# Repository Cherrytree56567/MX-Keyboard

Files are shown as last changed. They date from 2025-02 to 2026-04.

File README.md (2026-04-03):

# MX Keyboard
A Keyboard I made for Hackboard. It has a built-in USB C Hub and has Hotswap support.
gif

## Info
 - 0.25mm Tolerance
 - Black Case

## Features
 - USB C Hub
 - RP2040
 - 61 Keys
 - Cherry MX Switches
 - Kailh Hotswap Sockets

# CAD
Here are some photos of the CAD 3D Print. It uses M2 Threads that are 6mm long on the top (gray part) and a 1.6mm M2 nut on the bottom plate (blue part) to raise the pcb.
I made the USB-C input and output separate so that they won't be confused and I've used Durock V3 Stabilizers for the spacebar, enter and shift keys. When I made my mini
keyboard last time, I made the holes too tight, so when I soldered the keys, if it was slightly tilted, it wouldn't fit in the case. This time, I added a 1.5mm padding.
<br><br>






Here is a photo of pcb and the case put together without the keys.<br><br>


# PCB
Here are some photos of the PCB. I've made most of the main components to sit on the top, to prevent electromagnetic interference, and I've also uses ground fills.
The diodes and Kailh Hotswap sockets are placed under the board. The Git Repo was pretty messy because I had multiple revisions of the pcb and the case and I didn't
update some parts like the readme. It should be organised now. The wiring was pretty hard becuase it was my first time making a keyboard. I made a mini keyboard, but
there were some more things to worry about when making a full keyboard. I've used USB 2.0 because dealing with impedences was pretty difficult, and I didn't need a
USB 3.0 port anyway. If you want to take an upclose look at the pcb or the schematic, you can look the pdf's on the root of this repo.



pcb_schematic-1

# Firmware
Unfortunatly, I don't know if the code works, because I haven't gotten the PCB yet, but to install it:
 - Install Circuit Python
   - [Download CircuitPython](https://circuitpython.org/board/raspberry_pi_pico/)
   - Plug the Keyboard in
   - Drag the .uf2 into the RP2040 Drive
 - Install KMK
   - [Download KMK](https://github.com/KMKfw/kmk_firmware/archive/refs/heads/master.zip)
   - Unzip it and copy the `kmk` folder from `kmk_firmware-main` to the CIRCUITPY Drive
 - Install Firmware
   - Copy the Code from [src/main.py](https://github.com/Cherrytree56567/MX-Keyboard/raw/refs/heads/main/src/main.py)
   - Create a new file in the CIRCUITPY Drive called `code.py` and paste it in.

# Building
1. Print out the 3D Print and order the PCB
2. Solder all the parts on the PCB
3. Add the Kailh SMD Keys
4. Add the Durock V3 Stabilizers
5. Push the threads and nuts into the PCB using a Soldering Iron
6. Place the PCB in the case and screw it in
7. Install Firmware
<br>
Here is the JLC Ordering Screen


# Bill of Materials
> [!NOTE]
> All Prices are in USD

|Designator |Footprint |Quantity|Value |URL |Price_USD|
|---|---|---|---|---|---|
|C1, C2 |0402 |2 |15p |https://www.lcsc.com/product-detail/C86285.html |$0.36 |
|C10, C8 |0402 |2 |1u |https://www.lcsc.com/product-detail/C435415.html |$0.73 |
|C11, C12, C13, C14, C15, C16, C5, C6, C7, C9|0402 |10 |100n |https://www.lcsc.com/product-detail/C131394.html |$0.29 |
|C23, C24 |0805 |2 |10uF |https://www.lcsc.com/product-detail/C18185764.html |$0.39 |
|C25 |0805 |1 |100nF |https://www.lcsc.com/product-detail/C53084519.html |$0.29 |
|C3, C4 |0805 |2 |10u |https://www.lcsc.com/product-detail/C2167686.html |$0.61 |
|D1, D... |Diode_DO-35 |61 |Diode |https://www.lcsc.com/product-detail/C84410.html |$1.72 |
|D34 |1206 |1 |MBR120VLSFT1G |https://www.lcsc.com/product-detail/C223608.html |$0.70 |
|J1, J2, J4, J5 |USB_C_Receptacle_HRO_TYPE-C-31-M-12 |1 |USB_C_Receptacle_USB2.0|https://www.aliexpress.com/item/1005003285152827.html?mp=1|$4.01 |
|R1, R2 |0805 |2 |5.1K |https://www.lcsc.com/product-detail/C490833.html |$0.76 |
|R14, R15, R16, R17, R18, R19 |0805 |6 |56K |https://www.lcsc.com/product-detail/C21571499.html |$0.52 |
|R3, R5 |0402 |2 |1k |https://www.lcsc.com/product-detail/C852624.html |$0.86 |
|R4 |0402 |1 |DNF | |$0 |
|R6, R7 |0402 |2 |27 |https://www.aliexpress.com/item/1005005433144951.html?mp=1|$2.46 |
|S1 |MX_PCB_1.00u |65 |Key |https://www.aliexpress.com/item/1005003944834891.html?mp=1|$19.06 |
|SW1 |SW_Push_1P1T_NO_Vertical_Wuerth_434133025816|1 |SW_Push |https://www.lcsc.com/product-detail/C221897.html |$0.49 |
|U1 |SOIC-16_4.55x10.3mm_P1.27mm |1 |SL2.1A |https://www.aliexpress.com/item/1005005552905296.html?mp=1|$2.33 |
|U2 |SOT-223-3_TabPin2 |1 |NCP1117-3.3_SOT223 |https://www.lcsc.com/product-detail/C26537.html |$1.31 |
|U3 |SOIC-8_5.23x5.23mm_P1.27mm |1 |W25Q128JVS |https://www.aliexpress.com/item/1005008022185475.html |$4.88 |
|U4 |RP2040-QFN-56 |1 |RP2040 |https://www.lcsc.com/product-detail/C2040.html |$0.95 |
|Y1 |Crystal_SMD_3225-4Pin_3.2x2.5mm |1 |ABM8-272-T3 |https://www.lcsc.com/product-detail/C20625731.html |$1.45 |
|N/A |Standoff |4 |M2X6 |https://www.aliexpress.com/item/1005008551732587.html |$2.04 |
|N/A |Nut |12 |Nut |https://www.aliexpress.com/item/1005008755211193.html |$3.04 |
|N/A |Screw |5 |M2_10mm |https://www.ebay.com.au/itm/363744921549?var=632961986863 |$2.26 |
|N/A |Socket |70 |Kailh |https://www.aliexpress.com/item/1005007225352311.html?mp=1|$0.99 |
|N/A |Stabilizer |1 |Durock_V3_Stabilizers  |https://www.aliexpress.com/item/1005006628741999.html?mp=1|$15.56 |
|N/A |Key_Caps |1 |Black_Line_131 |https://www.aliexpress.com/item/1005007016258336.html?mp=1|$24.62 |
|N/A |PCB |1 |JLC_PCB |https://jlcpcb.com/ |$18.40 |
|N/A |JLCPCB Shipping |1 |JLCPCB_Shipping |https://www.jlcpcb.com |$12.73 |
|N/A |Aliexpress Tax |1 |ALIEXPRESS_TAX |https://www.aliexpress.com |$8.26 |
|N/A |LCSC Shipping |1 |LCSC_Shipping |https://www.lcsc.com |$12.81 |

Total Price: US$142.65

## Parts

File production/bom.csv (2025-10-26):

Designator | Footprint | Quantity | Value | LCSC Part #
C1, C2 | 0402 | 2 | 15p
C10, C8 | 0402 | 2 | 1u
C11, C12, C13, C14, C15, C16, C5, C6, C7, C9 | 0402 | 10 | 100n
C23, C24 | 0805 | 2 | 10uF
C25 | 0805 | 1 | 100nF
C3, C4 | 0805 | 2 | 10u
D1, D10, D11, D12, D13, D14, D15, D16, D17, D18, D19, D2, D20, D21, D22, D23, D24, D25, D26, D27, D28, D29, D3, D30, D31, D32, D33, D37, D38, D39, D4, D40, D41, D42, D43, D44, D45, D46, D47, D48, D49, D5, D50, D51, D52, D53, D54, D55, D56, D57, D58, D59, D6, D61, D63, D67, D7, D71, D72, D8, D9 | Diode_DO-35 | 61 | Diode
D34 | 1206 | 1 | SD1206T020S1R0
J1, J2, J4, J5 | USB_C_Receptacle_HRO_TYPE-C-31-M-12 | 4 | USB_C_Receptacle_USB2.0
R1, R2 | 0805 | 2 | 5.1K
R14, R15, R16, R17, R18, R19 | 0805 | 6 | 56K
R3, R5 | 0402 | 2 | 1k
R4 | 0402 | 1 | DNF
R6, R7 | 0402 | 2 | 27
S1 | SW_Hotswap_Kailh_MX_1.00u | 1 | esc
S10 | SW_Hotswap_Kailh_MX_1.00u | 1 | 3
S11 | SW_Hotswap_Kailh_MX_1.00u | 1 | e
S12 | SW_Hotswap_Kailh_MX_1.00u | 1 | d
S13 | SW_Hotswap_Kailh_MX_1.00u | 1 | 4
S14 | SW_Hotswap_Kailh_MX_1.00u | 1 | r
S15 | SW_Hotswap_Kailh_MX_1.00u | 1 | f
S16 | SW_Hotswap_Kailh_MX_1.00u | 1 | 5
S17 | SW_Hotswap_Kailh_MX_1.00u | 1 | t
S18 | SW_Hotswap_Kailh_MX_1.00u | 1 | g
S19 | SW_Hotswap_Kailh_MX_1.00u | 1 | 6
S2 | SW_Hotswap_Kailh_MX_1.00u | 1 | 1
S20 | SW_Hotswap_Kailh_MX_1.00u | 1 | y
S21 | SW_Hotswap_Kailh_MX_1.00u | 1 | h
S22 | SW_Hotswap_Kailh_MX_1.00u | 1 | 7
S23 | SW_Hotswap_Kailh_MX_1.00u | 1 | u
S24 | SW_Hotswap_Kailh_MX_1.00u | 1 | j
S25 | SW_Hotswap_Kailh_MX_1.00u | 1 | 8
S26 | SW_Hotswap_Kailh_MX_1.00u | 1 | i
S27 | SW_Hotswap_Kailh_MX_1.00u | 1 | k
S28 | SW_Hotswap_Kailh_MX_1.00u | 1 | 9
S29 | SW_Hotswap_Kailh_MX_1.00u | 1 | o
S3 | SW_Hotswap_Kailh_MX_1.00u | 1 | 2
S30 | SW_Hotswap_Kailh_MX_1.00u | 1 | l
S31 | SW_Hotswap_Kailh_MX_1.00u | 1 | 0
S32 | SW_Hotswap_Kailh_MX_1.00u | 1 | p
S33 | SW_Hotswap_Kailh_MX_1.00u | 1 | ;
S37 | SW_Hotswap_Kailh_MX_1.00u | 1 | -
S38 | SW_Hotswap_Kailh_MX_1.00u | 1 | [
S39 | SW_Hotswap_Kailh_MX_1.00u | 1 | '
S4 | SW_Hotswap_Kailh_MX_1.00u | 1 | tab
S40 | SW_Hotswap_Kailh_MX_1.00u | 1 | =
S41 | SW_Hotswap_Kailh_MX_1.00u | 1 | ]
S42 | SW_Hotswap_Kailh_MX_2.25u | 1 | enter
S43 | SW_Hotswap_Kailh_MX_2.00u | 1 | shift
S44 | SW_Hotswap_Kailh_MX_1.25u | 1 | ctrl
S45 | SW_Hotswap_Kailh_MX_1.00u | 1 | z
S46 | SW_Hotswap_Kailh_MX_1.25u | 1 | windows
S47 | SW_Hotswap_Kailh_MX_1.00u | 1 | x
S48 | SW_Hotswap_Kailh_MX_1.25u | 1 | alt
S49 | SW_Hotswap_Kailh_MX_1.00u | 1 | c
S5 | SW_Hotswap_Kailh_MX_1.00u | 1 | q
S50 | SW_Hotswap_Kailh_MX_6.25u | 1 | space
S51 | SW_Hotswap_Kailh_MX_1.00u | 1 | v
S52 | SW_Hotswap_Kailh_MX_1.25u | 1 | altright
S53 | SW_Hotswap_Kailh_MX_1.00u | 1 | b
S54 | SW_Hotswap_Kailh_MX_1.25u | 1 | windowsright
S55 | SW_Hotswap_Kailh_MX_1.00u | 1 | n
S56 | SW_Hotswap_Kailh_MX_1.00u | 1 | page
S57 | SW_Hotswap_Kailh_MX_1.00u | 1 | m
S58 | SW_Hotswap_Kailh_MX_1.25u | 1 | ctrlright
S59 | SW_Hotswap_Kailh_MX_1.00u | 1 | ,
S6 | SW_Hotswap_Kailh_MX_1.00u | 1 | w
S61 | SW_Hotswap_Kailh_MX_1.00u | 1 | .
S63 | SW_Hotswap_Kailh_MX_1.00u | 1 | /
S67 | SW_Hotswap_Kailh_MX_2.75u | 1 | shiftright
S7 | SW_Hotswap_Kailh_MX_1.00u | 1 | caps
S71 | SW_Hotswap_Kailh_MX_1.75u | 1 | backspace
S72 | SW_Hotswap_Kailh_MX_1.25u | 1 | \
S8 | SW_Hotswap_Kailh_MX_1.00u | 1 | a
S9 | SW_Hotswap_Kailh_MX_1.00u | 1 | s
SW1 | SW_Push_1P1T_NO_Vertical_Wuerth_434133025816 | 1 | SW_Push
U1 | SOIC-16_4.55x10.3mm_P1.27mm | 1 | SL2.1A
U2 | SOT-223-3_TabPin2 | 1 | NCP1117-3.3_SOT223
U3 | SOIC-8_5.3x5.3mm_P1.27mm | 1 | W25Q128JVS
U4 | RP2040-QFN-56 | 1 | RP2040
Y1 | Crystal_SMD_3225-4Pin_3.2x2.5mm | 1 | ABM8-272-T3

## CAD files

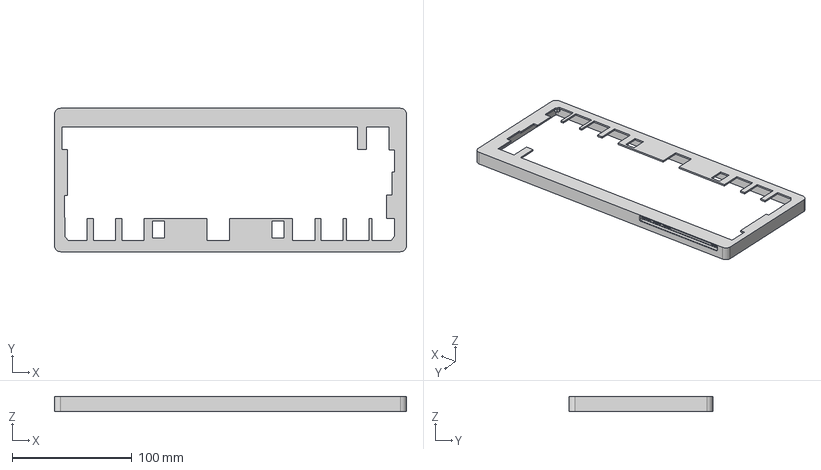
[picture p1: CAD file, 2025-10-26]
3D Case/Part Studio 1 - Part 2.step
294.6 x 120.1 x 12.5 mm

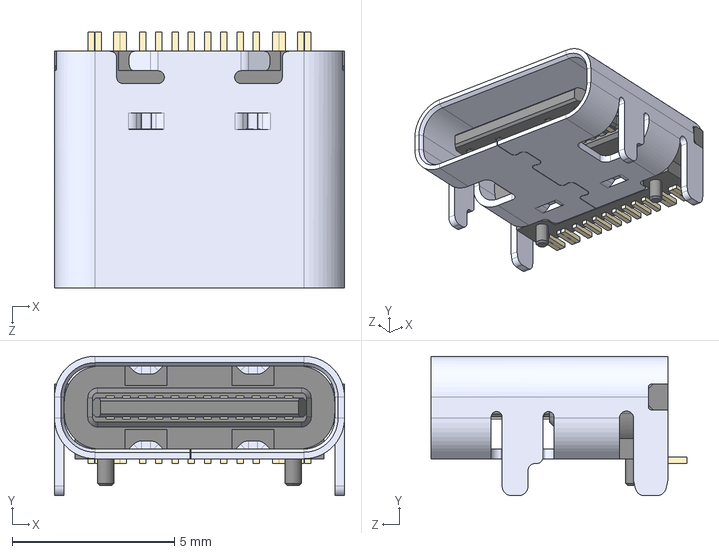
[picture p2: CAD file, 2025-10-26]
pcb/3D Models/TYPE-C-31-M-12--3DModel-STEP-56544.STEP
8.94 x 4.30 x 7.90 mm

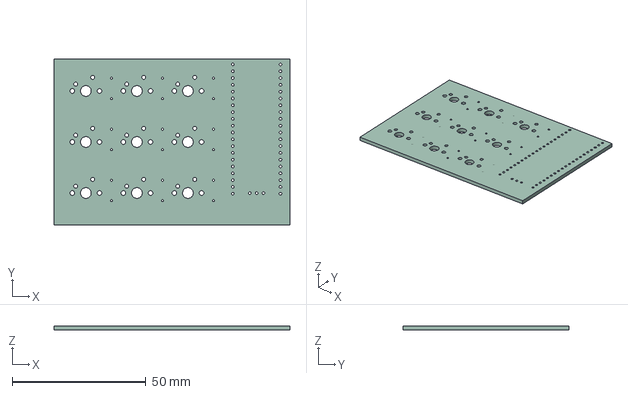
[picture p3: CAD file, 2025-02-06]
pcb/pcb.step
88.1 x 61.9 x 1.60 mm

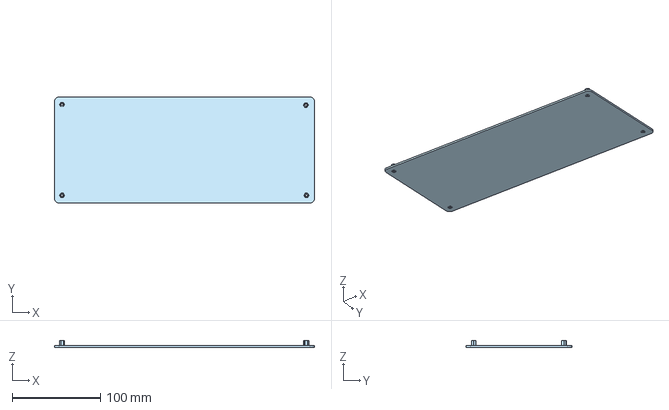
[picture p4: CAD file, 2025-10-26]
3D Case/Part Studio 1 - Part 1.step
294.6 x 120.1 x 7.90 mm

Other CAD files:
pcb/production/Part Studio 1 - Part 2.stl
production/Part Studio 1 - Part 2.stl
pcb/production/Part Studio 1 - Part 1.stl
production/Part Studio 1 - Part 1.stl
3D Case/PCB Ports.dwg
3D Case/PCB.dwg
3D Case/PCB Top.dwg
3D Case/Part Studio 1 - Part 2.stl
Animation/MX_Keyboard_Final.blend

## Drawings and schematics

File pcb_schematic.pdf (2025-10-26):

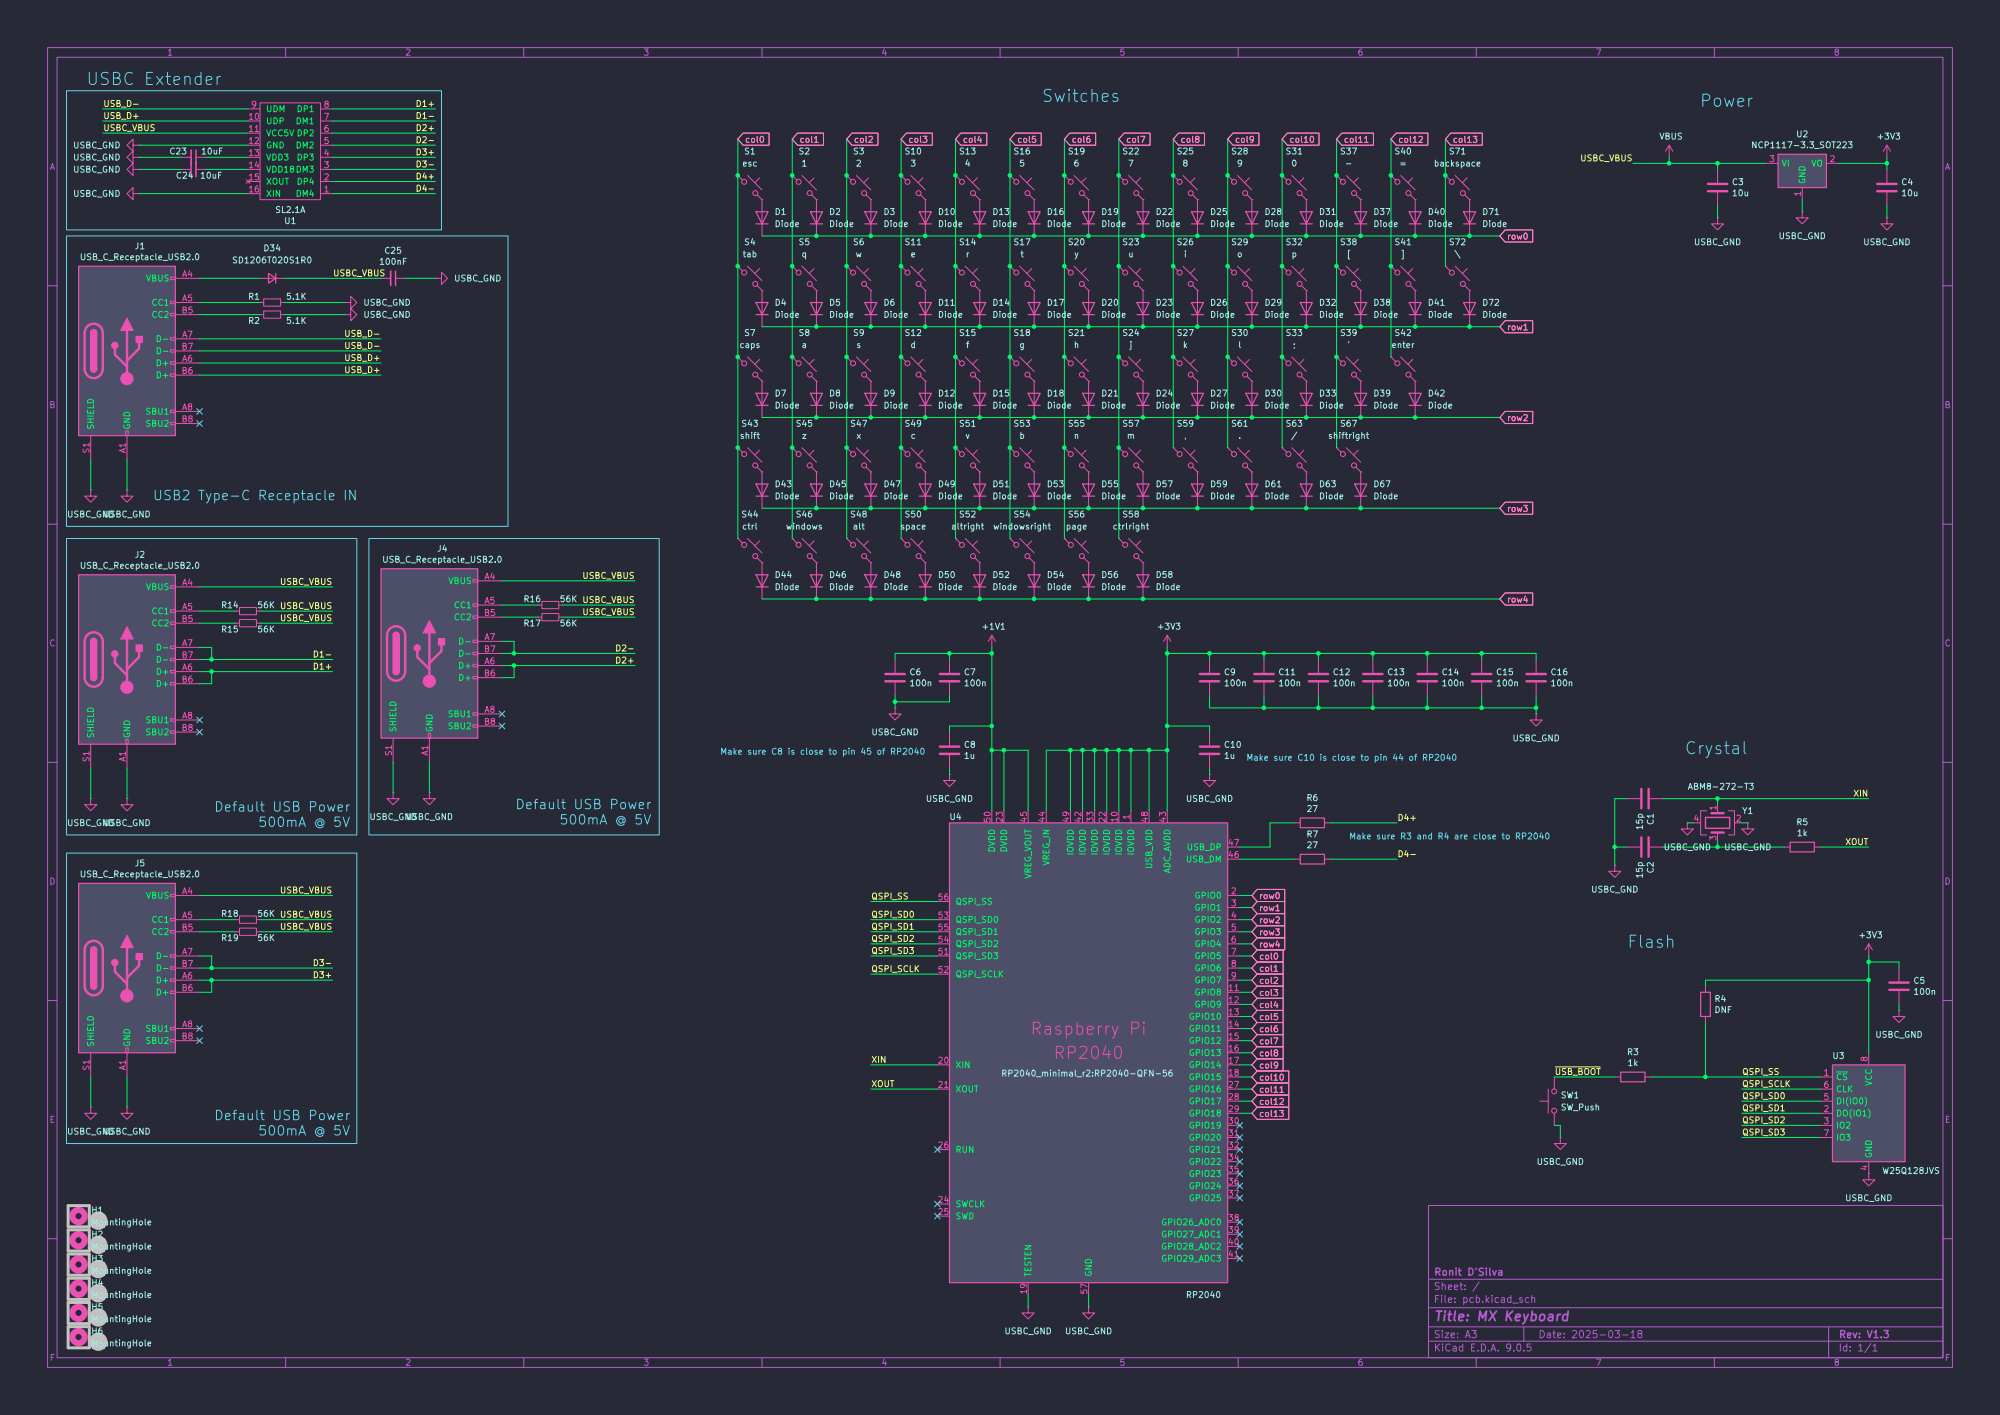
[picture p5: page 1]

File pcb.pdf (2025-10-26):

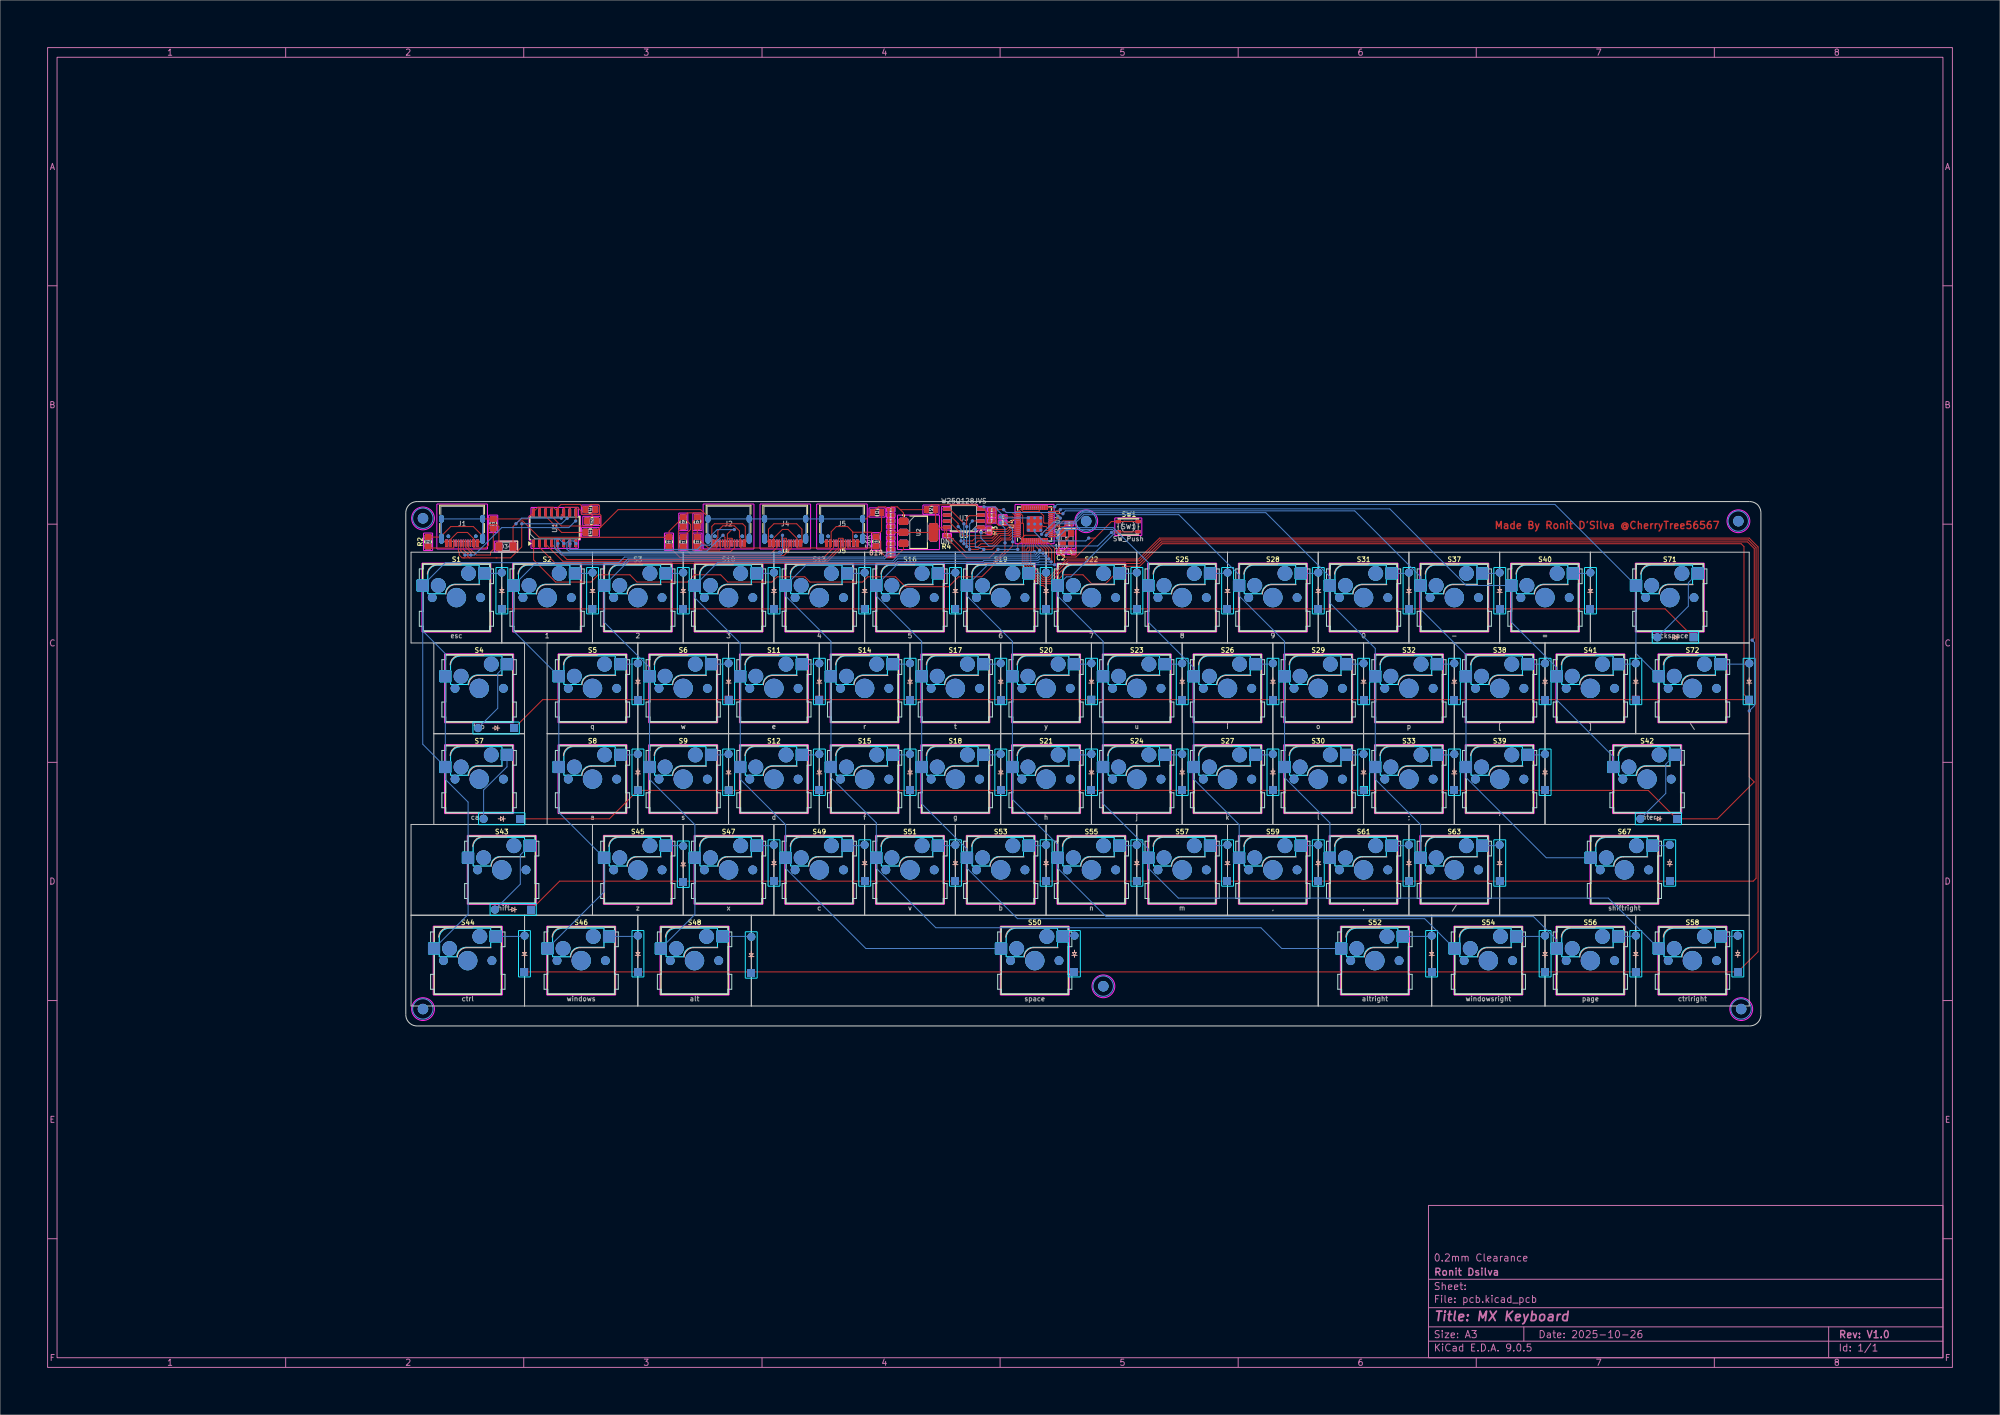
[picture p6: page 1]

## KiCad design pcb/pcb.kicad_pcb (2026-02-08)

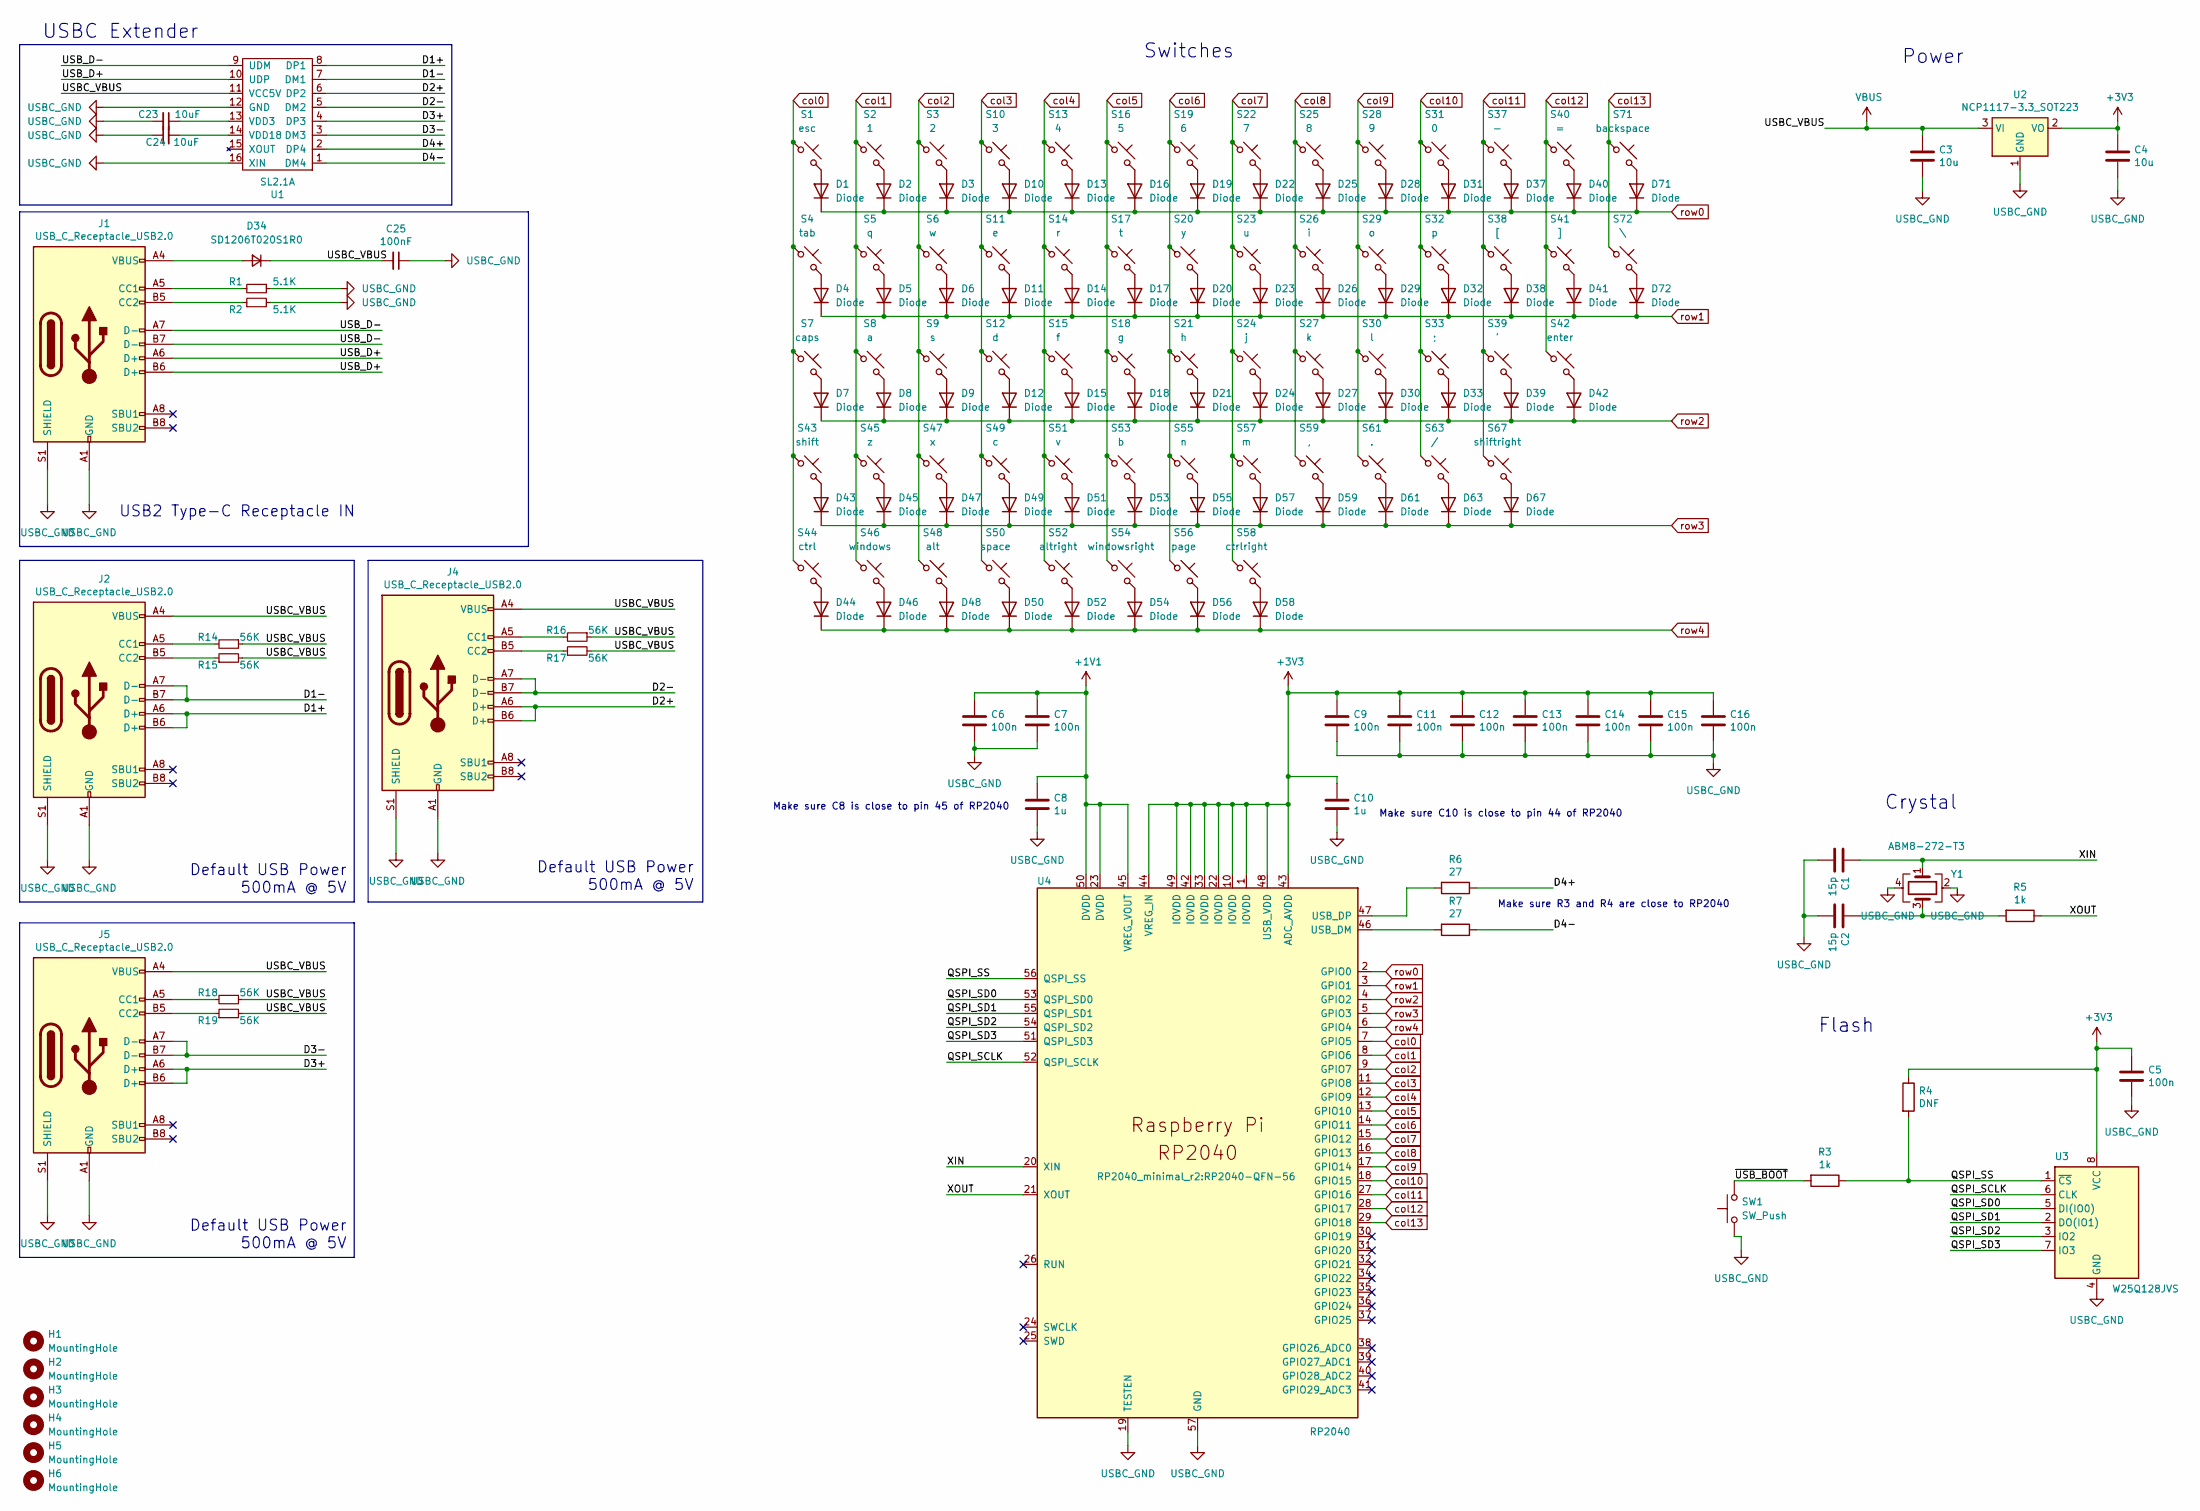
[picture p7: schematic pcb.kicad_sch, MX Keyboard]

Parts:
C1, C2: 15p; C_0402_1005Metric
C3, C4: 10u; C_0805_2012Metric
C5, C6, C7, C9, C11, C12, C13, C14, C15, C16: 100n; C_0402_1005Metric
C8, C10: 1u; C_0402_1005Metric
C23, C24: 10uF; C_0805_2012Metric_Pad1.18x1.45mm_HandSolder
C25: 100nF; C_0805_2012Metric_Pad1.18x1.45mm_HandSolder
D1, D2, D3, D4, D5, D6, D7, D8, D9, D10, D11, D12, D13, D14, D15, D16, D17, D18, D19, D20, D21, D22, D23, D24, D25, D26, D27, D28, D29, D30, D31, D32, D33, D37, D38, D39, D40, D41, D42, D43, D44, D45, D46, D47, D48, D49, D50, D51, D52, D53, D54, D55, D56, D57, D58, D59, D61, D63, D67, D71, D72: Diode; Diode_DO-35
D34: SD1206T020S1R0; D_1206_3216Metric_Pad1.42x1.75mm_HandSolder
H1, H2, H3, H4, H5, H6: MountingHole; MountingHole_2.1mm
J1, J2, J4, J5: USB_C_Receptacle_USB2.0; USB_C_Receptacle_HRO_TYPE-C-31-M-12
R1, R2: 5.1K; R_0805_2012Metric_Pad1.20x1.40mm_HandSolder
R3, R5: 1k; R_0402_1005Metric
R4: DNF; R_0402_1005Metric
R6, R7: 27; R_0402_1005Metric
R14, R15, R16, R17, R18, R19: 56K; R_0805_2012Metric_Pad1.20x1.40mm_HandSolder
S1: esc; SW_Hotswap_Kailh_MX_1.00u
S2: 1; SW_Hotswap_Kailh_MX_1.00u
S3: 2; SW_Hotswap_Kailh_MX_1.00u
S4: tab; SW_Hotswap_Kailh_MX_1.00u
S5: q; SW_Hotswap_Kailh_MX_1.00u
S6: w; SW_Hotswap_Kailh_MX_1.00u
S7: caps; SW_Hotswap_Kailh_MX_1.00u
S8: a; SW_Hotswap_Kailh_MX_1.00u
S9: s; SW_Hotswap_Kailh_MX_1.00u
S10: 3; SW_Hotswap_Kailh_MX_1.00u
S11: e; SW_Hotswap_Kailh_MX_1.00u
S12: d; SW_Hotswap_Kailh_MX_1.00u
S13: 4; SW_Hotswap_Kailh_MX_1.00u
S14: r; SW_Hotswap_Kailh_MX_1.00u
S15: f; SW_Hotswap_Kailh_MX_1.00u
S16: 5; SW_Hotswap_Kailh_MX_1.00u
S17: t; SW_Hotswap_Kailh_MX_1.00u
S18: g; SW_Hotswap_Kailh_MX_1.00u
S19: 6; SW_Hotswap_Kailh_MX_1.00u
S20: y; SW_Hotswap_Kailh_MX_1.00u
S21: h; SW_Hotswap_Kailh_MX_1.00u
S22: 7; SW_Hotswap_Kailh_MX_1.00u
S23: u; SW_Hotswap_Kailh_MX_1.00u
S24: j; SW_Hotswap_Kailh_MX_1.00u
S25: 8; SW_Hotswap_Kailh_MX_1.00u
S26: i; SW_Hotswap_Kailh_MX_1.00u
S27: k; SW_Hotswap_Kailh_MX_1.00u
S28: 9; SW_Hotswap_Kailh_MX_1.00u
S29: o; SW_Hotswap_Kailh_MX_1.00u
S30: l; SW_Hotswap_Kailh_MX_1.00u
S31: 0; SW_Hotswap_Kailh_MX_1.00u
S32: p; SW_Hotswap_Kailh_MX_1.00u
S33: ;; SW_Hotswap_Kailh_MX_1.00u
S37: -; SW_Hotswap_Kailh_MX_1.00u
S38: [; SW_Hotswap_Kailh_MX_1.00u
S39: '; SW_Hotswap_Kailh_MX_1.00u
S40: =; SW_Hotswap_Kailh_MX_1.00u
S41: ]; SW_Hotswap_Kailh_MX_1.00u
S42: enter; SW_Hotswap_Kailh_MX_2.25u
S43: shift; SW_Hotswap_Kailh_MX_2.00u
S44: ctrl; SW_Hotswap_Kailh_MX_1.25u
S45: z; SW_Hotswap_Kailh_MX_1.00u
S46: windows; SW_Hotswap_Kailh_MX_1.25u
S47: x; SW_Hotswap_Kailh_MX_1.00u
S48: alt; SW_Hotswap_Kailh_MX_1.25u
S49: c; SW_Hotswap_Kailh_MX_1.00u
S50: space; SW_Hotswap_Kailh_MX_6.25u
S51: v; SW_Hotswap_Kailh_MX_1.00u
S52: altright; SW_Hotswap_Kailh_MX_1.25u
S53: b; SW_Hotswap_Kailh_MX_1.00u
S54: windowsright; SW_Hotswap_Kailh_MX_1.25u
S55: n; SW_Hotswap_Kailh_MX_1.00u
S56: page; SW_Hotswap_Kailh_MX_1.00u
S57: m; SW_Hotswap_Kailh_MX_1.00u
S58: ctrlright; SW_Hotswap_Kailh_MX_1.25u
S59: ,; SW_Hotswap_Kailh_MX_1.00u
S61: .; SW_Hotswap_Kailh_MX_1.00u
S63: /; SW_Hotswap_Kailh_MX_1.00u
S67: shiftright; SW_Hotswap_Kailh_MX_2.75u
S71: backspace; SW_Hotswap_Kailh_MX_1.75u
S72: \; SW_Hotswap_Kailh_MX_1.25u
SW1: SW_Push; SW_Push_1P1T_NO_Vertical_Wuerth_434133025816
U1: SL2.1A; SOIC-16_4.55x10.3mm_P1.27mm
U2: NCP1117-3.3_SOT223; SOT-223-3_TabPin2
U3: W25Q128JVS; SOIC-8_5.3x5.3mm_P1.27mm
U4: RP2040; RP2040-QFN-56
Y1: ABM8-272-T3; Crystal_SMD_3225-4Pin_3.2x2.5mm

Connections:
+1V1: C6.1, C7.1, C8.1, U4.23 (DVDD), U4.45 (VREG_VOUT), U4.50 (DVDD)
+3V3: C4.1, C5.1, C9.1, C10.1, C11.1, C12.1, C13.1, C14.1, C15.1, C16.1, R4.1, U2.2 (VO), U3.8 (VCC), U4.1 (IOVDD), U4.10 (IOVDD), U4.22 (IOVDD), U4.33 (IOVDD), U4.42 (IOVDD), U4.43 (ADC_AVDD), U4.44 (VREG_IN), U4.48 (USB_VDD), U4.49 (IOVDD)
/D1+: J2.A6 (D+), J2.B6 (D+), U1.8 (DP1)
/D1-: J2.A7 (D-), J2.B7 (D-), U1.7 (DM1)
/D2+: J4.A6 (D+), J4.B6 (D+), U1.6 (DP2)
/D2-: J4.A7 (D-), J4.B7 (D-), U1.5 (DM2)
/D3+: J5.A6 (D+), J5.B6 (D+), U1.4 (DP3)
/D3-: J5.A7 (D-), J5.B7 (D-), U1.3 (DM3)
/D4+: R6.1, U1.2 (DP4)
/D4-: R7.1, U1.1 (DM4)
/QSPI_SCLK: U3.6 (CLK), U4.52 (QSPI_SCLK)
/QSPI_SD0: U3.5 (DI(IO0)), U4.53 (QSPI_SD0)
/QSPI_SD1: U3.2 (DO(IO1)), U4.55 (QSPI_SD1)
/QSPI_SD2: U3.3 (IO2), U4.54 (QSPI_SD2)
/QSPI_SD3: U3.7 (IO3), U4.51 (QSPI_SD3)
/QSPI_SS: R3.1, R4.2, U3.1 (~CS), U4.56 (QSPI_SS)
/USB_D+: J1.A6 (D+), J1.B6 (D+), U1.10 (UDP)
/USB_D-: J1.A7 (D-), J1.B7 (D-), U1.9 (UDM)
/XIN: C1.1, U4.20 (XIN), Y1.1
/XOUT: R5.1, U4.21 (XOUT)
/~USB_BOOT: R3.2, SW1.2
unnamed: C2.1, R5.2, Y1.3
unnamed: D1.2 (A), S1.2
unnamed: D2.2 (A), S2.2
unnamed: D3.2 (A), S3.2
unnamed: D4.2 (A), S4.2
unnamed: D5.2 (A), S5.2
unnamed: D6.2 (A), S6.2
unnamed: D7.2 (A), S7.2
unnamed: D8.2 (A), S8.2
unnamed: D9.2 (A), S9.2
unnamed: D10.2 (A), S10.2
unnamed: D11.2 (A), S11.2
unnamed: D12.2 (A), S12.2
unnamed: D13.2 (A), S13.2
unnamed: D14.2 (A), S14.2
unnamed: D15.2 (A), S15.2
unnamed: D16.2 (A), S16.2
unnamed: D17.2 (A), S17.2
unnamed: D18.2 (A), S18.2
unnamed: D19.2 (A), S19.2
unnamed: D20.2 (A), S20.2
unnamed: D21.2 (A), S21.2
unnamed: D22.2 (A), S22.2
unnamed: D23.2 (A), S23.2
unnamed: D24.2 (A), S24.2
unnamed: D25.2 (A), S25.2
unnamed: D26.2 (A), S26.2
unnamed: D27.2 (A), S27.2
unnamed: D28.2 (A), S28.2
unnamed: D29.2 (A), S29.2
unnamed: D30.2 (A), S30.2
unnamed: D31.2 (A), S31.2
unnamed: D32.2 (A), S32.2
unnamed: D33.2 (A), S33.2
unnamed: D34.2 (A), J1.A4 (VBUS), J1.A9 (VBUS), J1.B4 (VBUS), J1.B9 (VBUS)
unnamed: D37.2 (A), S37.2
unnamed: D38.2 (A), S38.2
unnamed: D39.2 (A), S39.2
unnamed: D40.2 (A), S40.2
unnamed: D41.2 (A), S41.2
unnamed: D42.2 (A), S42.2
unnamed: D43.2 (A), S43.2
unnamed: D44.2 (A), S44.2
unnamed: D45.2 (A), S45.2
unnamed: D46.2 (A), S46.2
unnamed: D47.2 (A), S47.2
unnamed: D48.2 (A), S48.2
unnamed: D49.2 (A), S49.2
unnamed: D50.2 (A), S50.2
unnamed: D51.2 (A), S51.2
unnamed: D52.2 (A), S52.2
unnamed: D53.2 (A), S53.2
unnamed: D54.2 (A), S54.2
unnamed: D55.2 (A), S55.2
unnamed: D56.2 (A), S56.2
unnamed: D57.2 (A), S57.2
unnamed: D58.2 (A), S58.2
unnamed: D59.2 (A), S59.2
unnamed: D61.2 (A), S61.2
unnamed: D63.2 (A), S63.2
unnamed: D67.2 (A), S67.2
unnamed: D71.2 (A), S71.2
unnamed: D72.2 (A), S72.2
unnamed: J1.A5 (CC1), R1.2
unnamed: J1.B5 (CC2), R2.1
unnamed: J2.A5 (CC1), R14.2
unnamed: J2.B5 (CC2), R15.1
unnamed: J4.A5 (CC1), R16.2
unnamed: J4.B5 (CC2), R17.1
unnamed: J5.A5 (CC1), R18.2
unnamed: J5.B5 (CC2), R19.1
unnamed: C23.1, U1.13 (VDD3)
unnamed: C24.2, U1.14 (VDD18)
unnamed: R7.2, U4.46 (USB_DM)
unnamed: R6.2, U4.47 (USB_DP)
USBC_GND: C1.2, C2.2, C3.2, C4.2, C5.2, C6.2, C7.2, C8.2, C9.2, C10.2, C11.2, C12.2, C13.2, C14.2, C15.2, C16.2, C23.2, C24.1, C25.1, J1.A1 (GND), J1.A12 (GND), J1.B1 (GND), J1.B12 (GND), J1.S1 (SHIELD), J2.A1 (GND), J2.A12 (GND), J2.B1 (GND), J2.B12 (GND), J2.S1 (SHIELD), J4.A1 (GND), J4.A12 (GND), J4.B1 (GND), J4.B12 (GND), J4.S1 (SHIELD), J5.A1 (GND), J5.A12 (GND), J5.B1 (GND), J5.B12 (GND), J5.S1 (SHIELD), R1.1, R2.2, SW1.1, U1.12 (GND), U1.16 (XIN), U2.1 (GND), U3.4 (GND), U4.19 (TESTEN), U4.57 (GND), Y1.2, Y1.4
VBUS: C3.1, C25.2, D34.1 (K), J2.A4 (VBUS), J2.A9 (VBUS), J2.B4 (VBUS), J2.B9 (VBUS), J4.A4 (VBUS), J4.A9 (VBUS), J4.B4 (VBUS), J4.B9 (VBUS), J5.A4 (VBUS), J5.A9 (VBUS), J5.B4 (VBUS), J5.B9 (VBUS), R14.1, R15.2, R16.1, R17.2, R18.1, R19.2, U1.11 (VCC5V), U2.3 (VI)
col0: S1.1, S4.1, S7.1, S43.1, S44.1, U4.7 (GPIO5)
col1: S2.1, S5.1, S8.1, S45.1, S46.1, U4.8 (GPIO6)
col2: S3.1, S6.1, S9.1, S47.1, S48.1, U4.9 (GPIO7)
col3: S10.1, S11.1, S12.1, S49.1, S50.1, U4.11 (GPIO8)
col4: S13.1, S14.1, S15.1, S51.1, S52.1, U4.12 (GPIO9)
col5: S16.1, S17.1, S18.1, S53.1, S54.1, U4.13 (GPIO10)
col6: S19.1, S20.1, S21.1, S55.1, S56.1, U4.14 (GPIO11)
col7: S22.1, S23.1, S24.1, S57.1, S58.1, U4.15 (GPIO12)
col8: S25.1, S26.1, S27.1, S59.1, U4.16 (GPIO13)
col9: S28.1, S29.1, S30.1, S61.1, U4.17 (GPIO14)
col10: S31.1, S32.1, S33.1, S63.1, U4.18 (GPIO15)
col11: S37.1, S38.1, S39.1, S67.1, U4.27 (GPIO16)
col12: S40.1, S41.1, S42.1, U4.28 (GPIO17)
col13: S71.1, S72.1, U4.29 (GPIO18)
row0: D1.1 (K), D2.1 (K), D3.1 (K), D10.1 (K), D13.1 (K), D16.1 (K), D19.1 (K), D22.1 (K), D25.1 (K), D28.1 (K), D31.1 (K), D37.1 (K), D40.1 (K), D71.1 (K), U4.2 (GPIO0)
row1: D4.1 (K), D5.1 (K), D6.1 (K), D11.1 (K), D14.1 (K), D17.1 (K), D20.1 (K), D23.1 (K), D26.1 (K), D29.1 (K), D32.1 (K), D38.1 (K), D41.1 (K), D72.1 (K), U4.3 (GPIO1)
row2: D7.1 (K), D8.1 (K), D9.1 (K), D12.1 (K), D15.1 (K), D18.1 (K), D21.1 (K), D24.1 (K), D27.1 (K), D30.1 (K), D33.1 (K), D39.1 (K), D42.1 (K), U4.4 (GPIO2)
row3: D43.1 (K), D45.1 (K), D47.1 (K), D49.1 (K), D51.1 (K), D53.1 (K), D55.1 (K), D57.1 (K), D59.1 (K), D61.1 (K), D63.1 (K), D67.1 (K), U4.5 (GPIO3)
row4: D44.1 (K), D46.1 (K), D48.1 (K), D50.1 (K), D52.1 (K), D54.1 (K), D56.1 (K), D58.1 (K), U4.6 (GPIO4)

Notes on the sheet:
Make sure C8 is close to pin 45 of RP2040
Default USB Power 500mA @ 5V
Make sure C10 is close to pin 44 of RP2040
USBC Extender
Switches
Make sure R3 and R4 are close to RP2040
Flash
Power
USB2 Type-C Receptacle IN
Crystal

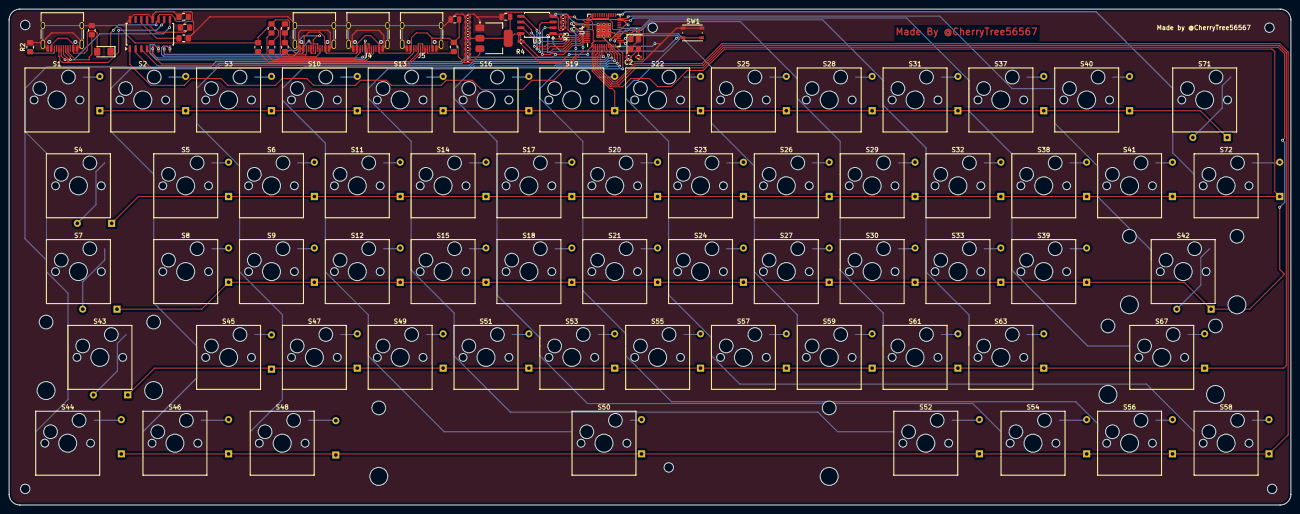
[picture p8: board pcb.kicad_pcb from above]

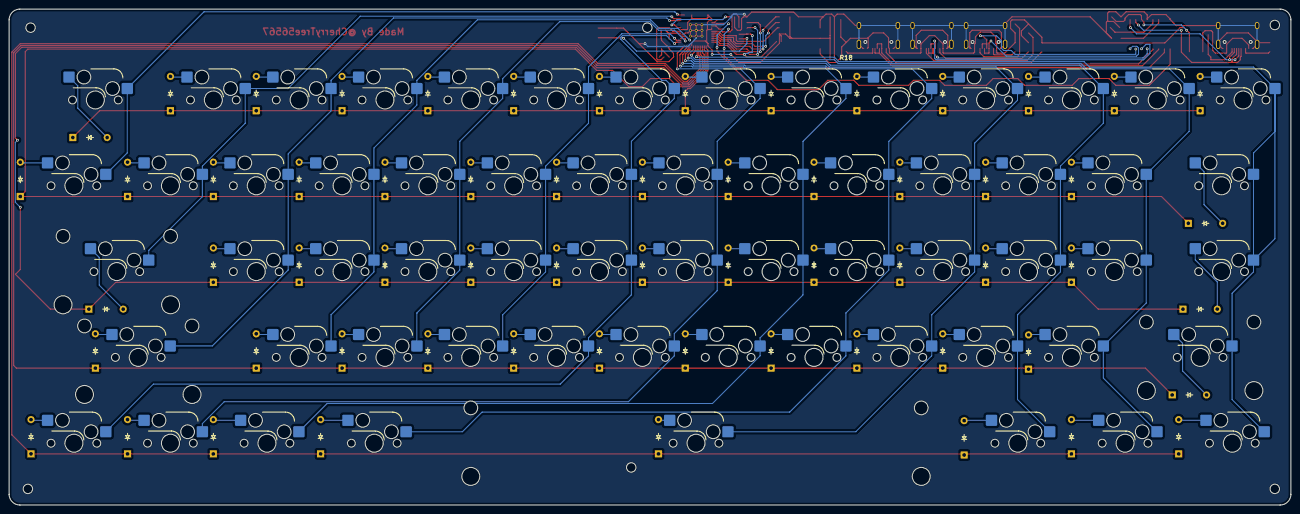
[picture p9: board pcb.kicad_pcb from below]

Board: 2 copper layers, 284.6 x 110.1 mm, 171 parts (61 on the bottom side), 117 nets.

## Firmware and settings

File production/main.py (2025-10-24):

from kmk.kmk_keyboard import KMKKeyboard
from kmk.keys import KC
from kmk.modules.layers import Layers

from kmk.extensions.lock_status import LockStatus

import board
import digitalio

keyboard = KMKKeyboard()
keyboard.modules.append(Layers())
keyboard.extensions.append(LockStatus())

keyboard.row_pins = [board.GP0, board.GP1, board.GP2, board.GP3, board.GP4]
keyboard.col_pins = [
    board.GP5, board.GP6, board.GP7, board.GP8, board.GP9, board.GP10, board.GP11, board.GP12, board.GP13, board.GP14, board.GP15, board.GP17, board.GP18
]

keyboard.keymap = [
    [KC.ESC, KC.ONE, KC.TWO, KC.THREE, KC.FOUR, KC.FIVE, KC.SIX, KC.SEVEN, KC.EIGHT, KC.NINE, KC.ZERO, KC.MINUS, KC.EQUAL, KC.BSPC],
    [KC.TAB, KC.Q, KC.W, KC.E, KC.R, KC.T, KC.Y, KC.U, KC.I, KC.O, KC.P, KC.LBRACKET, KC.RBRACKET, KC.BSLS],
    [KC.CAPS, KC.A, KC.S, KC.D, KC.F, KC.G, KC.H, KC.J, KC.K, KC.L, KC.SCLN, KC.QUOT, KC.ENT],
    [KC.LSFT, KC.Z, KC.X, KC.C, KC.V, KC.B, KC.N, KC.M, KC.COMM, KC.DOT, KC.SLSH, KC.RSFT],
    [KC.LCTL, KC.LGUI, KC.LALT, KC.SPC, KC.RALT, KC.RGUI, KC.APP, KC.RCTL]
]

if __name__ == '__main__':
    keyboard.go()

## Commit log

2025-02-08 curved pcb
    [pcb.kicad_pcb]
2025-02-08 Added Mounting Holes
    [pcb.kicad_pcb]
2025-02-10 Added Proper Support
    [pcb.kicad_pcb, pcb.kicad_sch, pcbONLYPCB.step]
2025-02-13 Added Case Parts
    [PCB Ports.dwg, PCB Top.dwg, PCB.dwg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]
2025-02-20 Added BOM and animations
    [MX_Keyboard_Final.blend]
2025-03-16 Added Modifications
    [MX_Keyboard_Final.blend, Part Studio 1 - Part 1.stl, Part Studio 1 - Part 2.stl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]
2025-10-24 Update switch type and replace an image in README
2025-10-24 Fixed 3D Case and noise
    [Part Studio 1 - Part 1.stl, Part Studio 1 - Part 2.stl, pcb.kicad_pcb]
2025-10-26 Revise BOM with component URLs and cleanup
    Updated BOM to include URLs for components and removed unused entries.
    [bom.csv]
2025-10-26 Fixed Traces
    [Part Studio 1 - Part 1.stl, Part Studio 1 - Part 2.stl, bom.csv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]
2025-10-26 Fixed Plate
    [Part Studio 1 - Part 1.stl, Part Studio 1 - Part 2.stl]
2025-10-26 Add shipping entries to BOM CSV
    [bom.csv]
2026-02-08 Added Silkscreen Username
    [pcb.kicad_pcb]
